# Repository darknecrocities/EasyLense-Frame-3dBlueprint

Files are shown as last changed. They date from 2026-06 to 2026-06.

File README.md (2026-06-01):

# ESP32-CAM Smart Glasses CAD Project (KCL)

An open-source, parametrically-designed, 3D-printable smart glasses frame built using **KCL (KittyCAD Language)**. This project houses two design iterations (`version1` and `version2`) of smart glasses optimized for housing an **ESP32-CAM**, rechargeable battery, charger modules, and custom routing pathways.

---

## 🕶️ Project Overview

This project provides a fully parametric CAD blueprint and print package for creating DIY smart glasses. By leveraging KCL's scripting capabilities, all clearances, frame dimensions, temple lengths, and fastener socket sizes can be customized by simply tweaking variables in the parameters file.

### Key Features
- **ESP32-CAM Integration**: Optimized compartment in the right temple to hold the microcontroller board securely.
- **Parametric Ergonomics**: Dynamic temple toe-in angle, bridge width, lens dimensions, and frame thicknesses.
- **Wire Routing & Cable Management**: Built-in strain reliefs, entry reliefs, and wiring channels for routing cables from the front frame camera to the controllers.
- **Exploded Service & Showcase Views**: Presentation layers in KCL showing how components fit together, complete with dimension annotations and fastener calls.
- **Tolerance Calibration**: Test coupons to verify printer tolerances before committing to full multi-hour temple prints.

---

## 📁 Repository Structure

The project is split into two versions, representing the evolution from a presentation-heavy assembly mockup to a print-optimized, tolerance-calibrated iteration:

```
tutorial-project/
├── version1/                      # Complete Assembly & Showcase Mockup
│   ├── main.kcl                   # Main presentation entrypoint
│   ├── parameters.kcl             # Global design variables (colors, sizes)
│   ├── front_frame.kcl            # Front glass frame CAD model
│   ├── left_temple.kcl            # Left temple arm CAD model
│   ├── right_temple.kcl           # Right temple arm (ESP32-CAM pocket)
│   ├── left_covers.kcl            # Covers for the left temple compartment
│   ├── right_covers.kcl           # Covers for the right temple compartment
│   ├── hardware.kcl               # M2 screws and heat-set insert mockups
│   ├── front_electronics.kcl      # Camera/sensor electronics model
│   ├── left_electronics.kcl       # Battery housing electronics model
│   ├── right_electronics.kcl      # ESP32-CAM board/connector models
│   ├── finished_showcase.kcl      # Closed render layout of the glasses
│   ├── dimension_blueprint.kcl    # Blueprints showing dimensional annotations
│   ├── fastener_callouts.kcl      # Assembly callouts pointing to hardware positions
│   ├── print_orientation_layout.cl# Printable parts FDM bed alignment layout
│   └── project.toml               # KCL project configuration
│
└── version2/                      # Print-Optimized & Tolerance-Calibrated Package
    ├── main.kcl                   # Minimal entrypoint showing print-ready parts
    ├── parameters.kcl             # Refined parameters with wearable toe-in angles
    ├── esp32_tolerance_coupon.kcl # Clearances test coupon for ESP32 compartment
    ├── front_frame.kcl            # Updated front frame with refined camera mounts
    ├── left_temple.kcl            # Left temple arm with refined clearances
    ├── right_temple.kcl           # Right temple arm with optimized ventilation slots
    ├── left_covers.kcl            # Left compartment covers
    ├── right_covers.kcl           # Right compartment covers
    ├── printable_assembly.kcl     # Printable part assembly references
    ├── print_ready_parts.kcl      # Flattened print layout configuration
    └── project.toml               # KCL project configuration
```

---

## 🔧 Design Iterations

### Version 1: Exploded Showcase & Assembly Blueprint
- **Focus**: Modeling the complete system architecture, assembly visualization, and presentation graphics.
- **Assembly View**: Features an exploded service view separating hardware, electronics, covers, and structural arms.
- **Dimensioning**: Contains blueprint overlays depicting model specifications.
- **Fasteners**: Includes interactive lines/annotations identifying mounting positions for M2 screws.

### Version 2: Print & Fit Calibration (Production Focus)
- **Focus**: Optimizing the design for real-world FDM 3D printing and fit comfort.
- **Wearable Fit**: Introduces ergonomic parameters like `wearableTempleToeInAngle` (defaulting to `3deg`) to curve the temples slightly inward for a secure fit on the wearer's head.
- **ESP32 Compartment Calibration**: Includes the `esp32_tolerance_coupon.kcl` test print. This creates a small compartment replica containing:
  - FDM clearance test posts.
  - Cover slide rails and M2 pilot holes.
  - Vent slot sizes and wire hooks.
  - USB charging board standoffs.
  *Use this test coupon to verify your printer's dimensional accuracy before printing the entire right temple.*
- **Print Optimization**: Simplified main assembly files to target clean `.STL`/`.STEP` output layouts.

---

## 🛠️ Usage Instructions

### 1. View & Edit in KittyCAD/KCL Editor
You can load these files into any KCL-compatible modeling viewer or the KittyCAD editor:
- Open `version1/main.kcl` to view the comprehensive presentation layout (includes showcase, exploded view, blueprints, and layouts).
- Open `version2/main.kcl` to view the final STL-ready, nested print layout.

### 2. Calibrating Tolerances (Version 2)
Prior to running a full print of the temples (which host thin walls and precise pockets):
1. Compile and print the coupon model in `version2/esp32_tolerance_coupon.kcl`.
2. Check the fitment of your ESP32-CAM board, wire routes, and sliding cover pieces.
3. If necessary, adjust tolerances in `version2/parameters.kcl` (e.g., `espFdmFitClearance`, `wallThickness`, `m2HeatSetInsertHoleDiameter`).

### 3. Slicing and Printing
- Export the parts from KCL (supports STEP, STL, and other formats).
- Recommended Slicing Settings:
  - **Layer Height**: 0.15mm - 0.2mm
  - **Infill**: 20% - 30% (gyro/grid pattern)
  - **Supports**: Required for the temple arms' internal pocket overhangs depending on orientation.
  - **Material**: PLA/PETG (recommended matte black or charcoal colors like the specified parameter HEX values).

---

## 🔩 Hardware & Bill of Materials (BOM)

- **Microcontroller**: ESP32-CAM board (approx. 43mm x 28mm).
- **USB Board**: Micro-USB or USB-C LiPo charger board (e.g., TP4056).
- **Battery**: Slim lithium-polymer rechargeable battery.
- **Screws**: M2 screws (typically 10mm length for covers).
- **Inserts**: M2 threaded heat-set inserts (3.5mm outer diameter, 4mm length).

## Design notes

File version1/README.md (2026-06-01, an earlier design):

# Smart Glasses Prototype - Version 1 (Mockup & Blueprint Assembly)

This directory contains the initial architectural mockup of the ESP32-CAM smart glasses. It is structured to generate an informative, multi-panel CAD presentation containing:
1. **Assembled View**: The fully built glasses frame with electronics nested inside.
2. **Exploded View**: Displaced components (temples, covers, electronics, screws) showing how the assembly fits together.
3. **Blueprint Panels**: Projected dimensions and annotation blueprints.
4. **Fastener Callouts**: Visual callouts illustrating screw and insert targets.
5. **Showcase Shell**: A render-ready closed configuration.
6. **Print Layout**: Parts nested onto a standard 220mm x 220mm FDM bed.

## 🚀 Entry Point

To render the full design presentation, run or compile:
```bash
main.kcl
```

## 📁 File Structure

- **`main.kcl`**: The master orchestration script compiling all assemblies and displacement panels.
- **`parameters.kcl`**: Design parameters (e.g., lens size, frame width, color codes).
- **`front_frame.kcl`**: Front glasses frames.
- **`left_temple.kcl` / `right_temple.kcl`**: Side arms.
- **`left_covers.kcl` / `right_covers.kcl`**: Sliding compartment covers.
- **`front_electronics.kcl` / `left_electronics.kcl` / `right_electronics.kcl`**: Volumes representing the physical sensors, boards, and batteries.
- **`hardware.kcl`**: Screws, washers, and insert fasteners.
- **`dimension_blueprint.kcl`**: Dimensions overlays.
- **`fastener_callouts.kcl`**: Connector annotation panel.
- **`print_orientation_layout.kcl`**: Nested printable configuration.

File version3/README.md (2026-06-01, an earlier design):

# Smart Glasses Prototype - Version 2 (Production & Tolerance Testing)

This directory houses the optimized production package of the smart glasses. The focus has shifted from assembly illustration to manufacturing validation, print nesting, and improved ergonomic wearability.

## 🚀 Entry Point

To compile the flat print package of production parts:
```bash
main.kcl
```
*(This loads the layout from `print_ready_parts.kcl` containing the structural printable components).*

## 🧪 ESP32 Clearance Tolerance Coupon

To ensure your 3D printer successfully prints the pocket snaps, sliding covers, screw slots, and cable pathways:
1. Compile and print:
   ```bash
   esp32_tolerance_coupon.kcl
   ```
2. Fit your ESP32-CAM and LiPo charging boards into the printed coupon.
3. Verify that cover panels slide in smoothly.
4. If adjustments are required, update variables in `parameters.kcl` and reprint the coupon before printing the full frame.

## 📁 Key File Changes vs Version 1

- **`parameters.kcl`**: Refined tolerances and added ergonomic `wearableTempleToeInAngle` (3deg) to fold temple tips slightly inward for a better head-fit.
- **`esp32_tolerance_coupon.kcl`**: The calibration tray representing a snippet of the controller pocket.
- **`print_ready_parts.kcl`**: Clean, printable component arrangement for slicing.

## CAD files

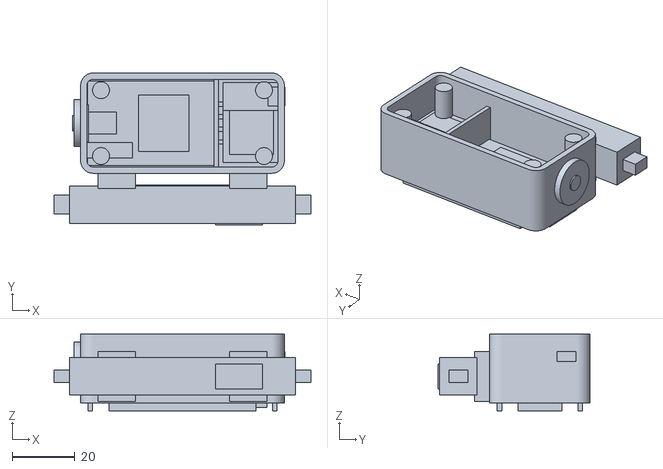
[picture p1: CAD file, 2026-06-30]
version4/main.stl
82.0 x 48.5 x 24.6

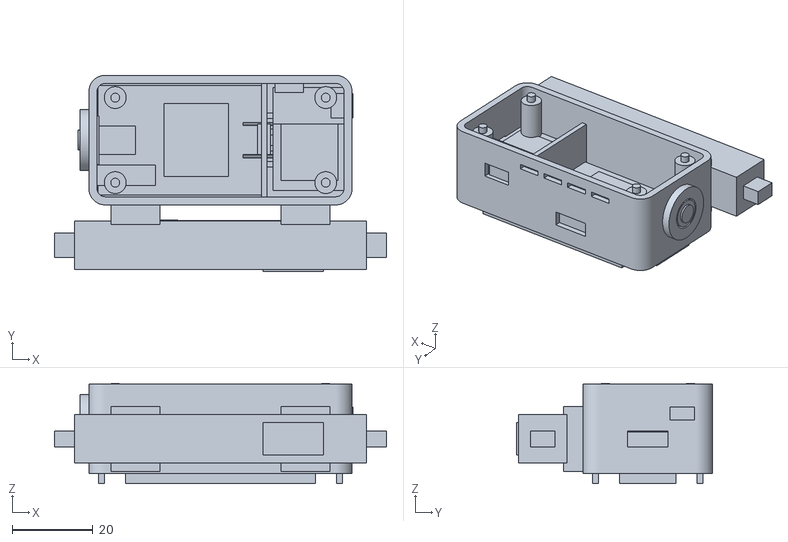
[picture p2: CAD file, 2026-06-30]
version4/complete_parts_exploded.stl
82.0 x 48.5 x 24.7

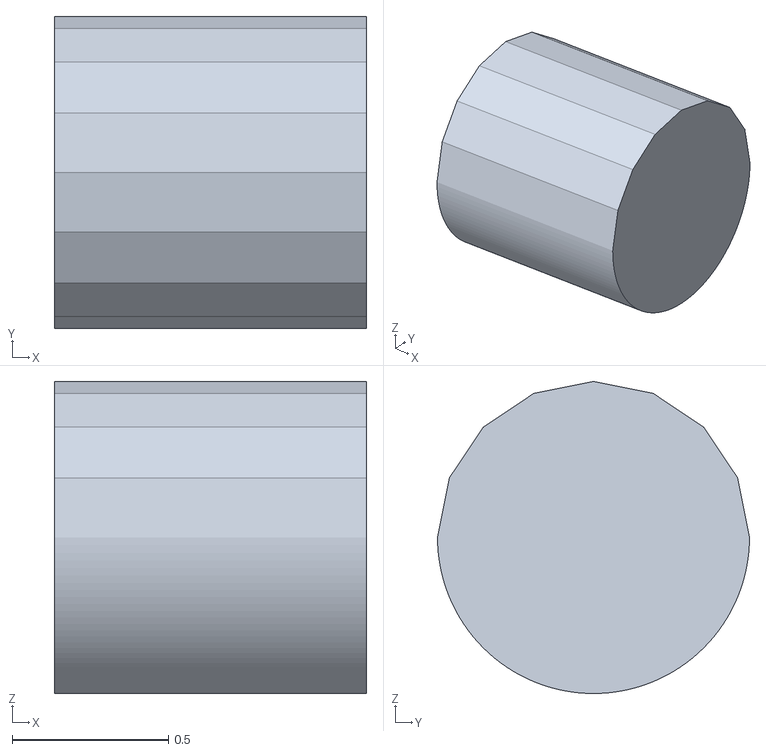
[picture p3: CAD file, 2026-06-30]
version4/unit_cyl_x.stl
1.00 x 1.00 x 1.00

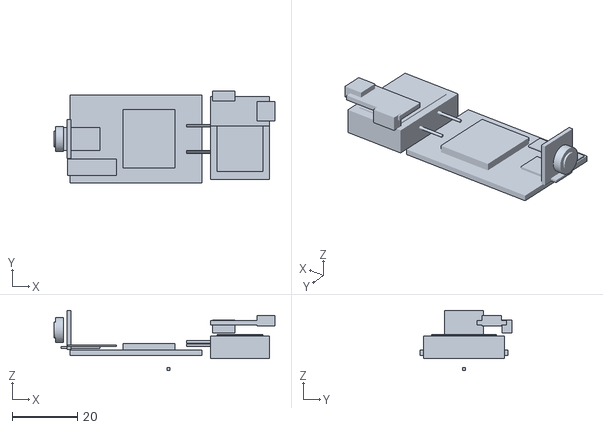
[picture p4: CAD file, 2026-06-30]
version4/electronics_placeholders.stl
67.9 x 28.2 x 18.5

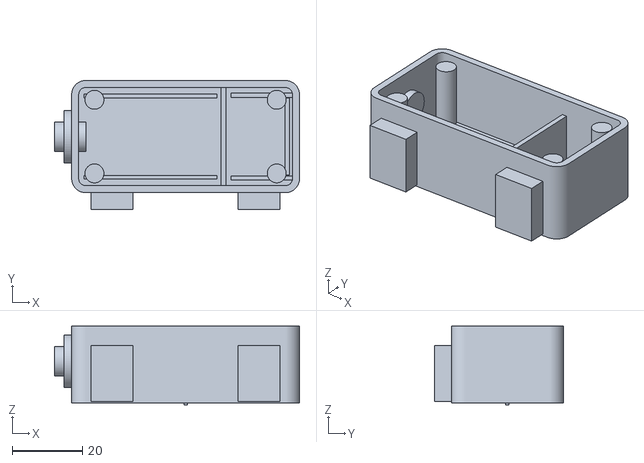
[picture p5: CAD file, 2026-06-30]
version4/smart_glasses_base.stl
69.9 x 36.8 x 22.5

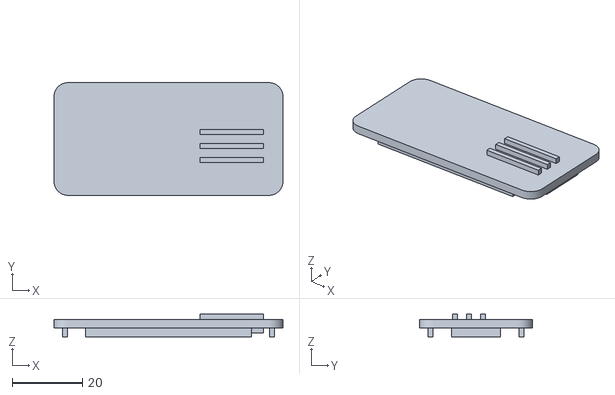
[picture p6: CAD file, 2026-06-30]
version4/smart_glasses_lid.stl
65.0 x 32.0 x 6.45

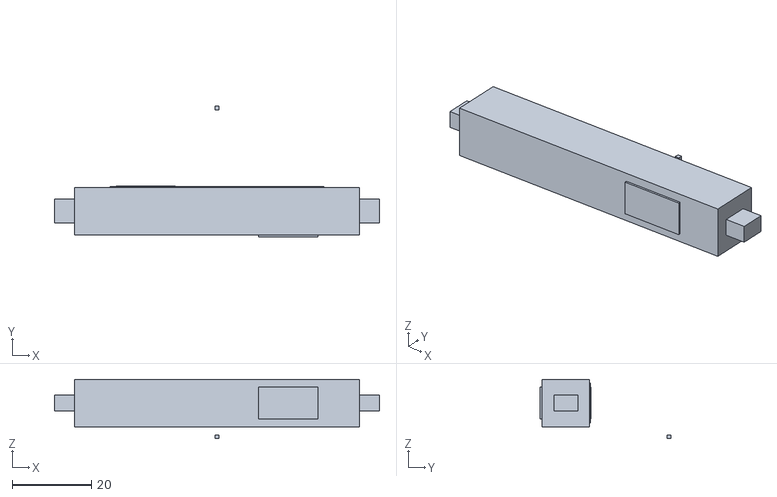
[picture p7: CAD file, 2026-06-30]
version4/velcro_mount_visual.stl
82.0 x 33.0 x 15.0

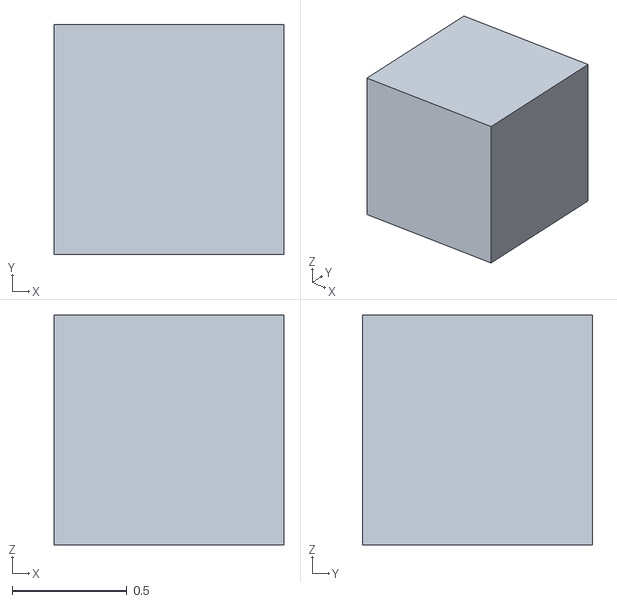
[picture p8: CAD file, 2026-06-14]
version4/unit_box.stl
1.00 x 1.00 x 1.00

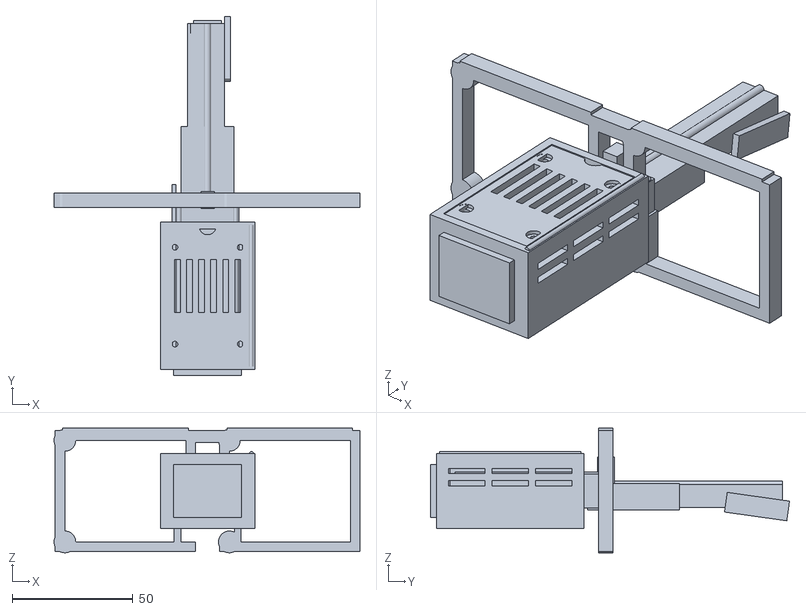
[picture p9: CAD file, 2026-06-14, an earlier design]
version3/main.stl
126.5 x 148.4 x 51.5

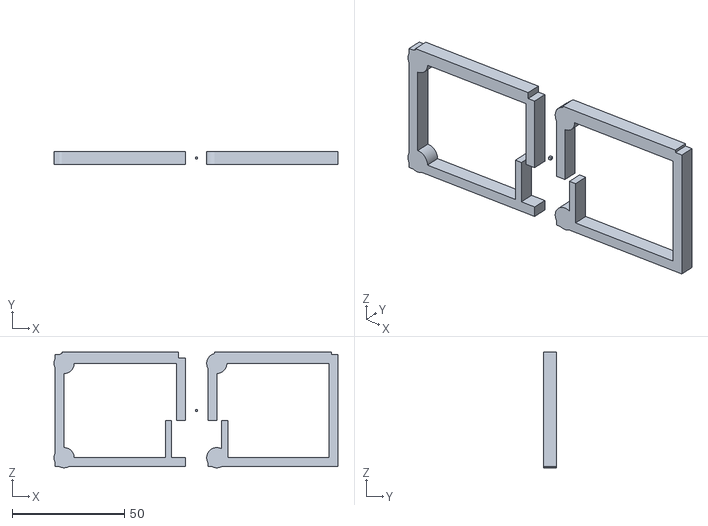
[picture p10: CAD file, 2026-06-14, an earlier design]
version3/front_frame.stl
126.5 x 6.00 x 51.5

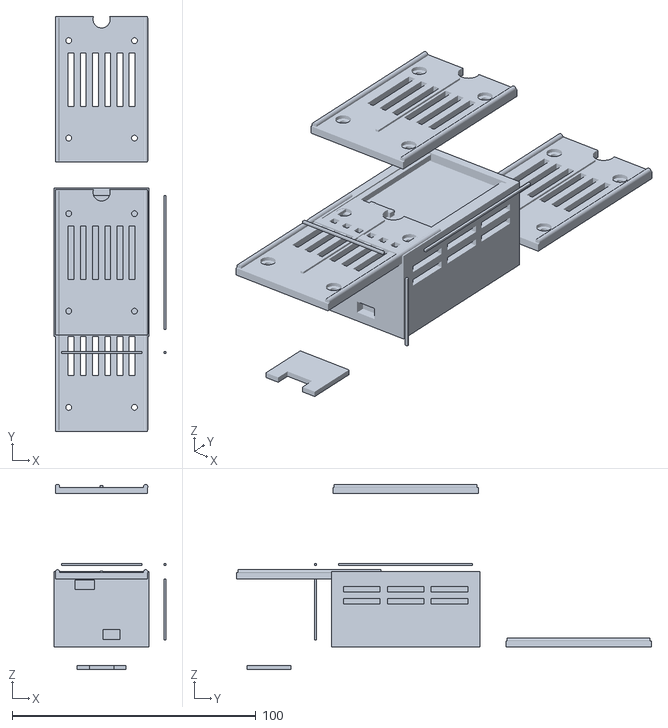
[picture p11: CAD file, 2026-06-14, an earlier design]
version3/esp32_tolerance_coupon.stl
45.9 x 170.3 x 76.1

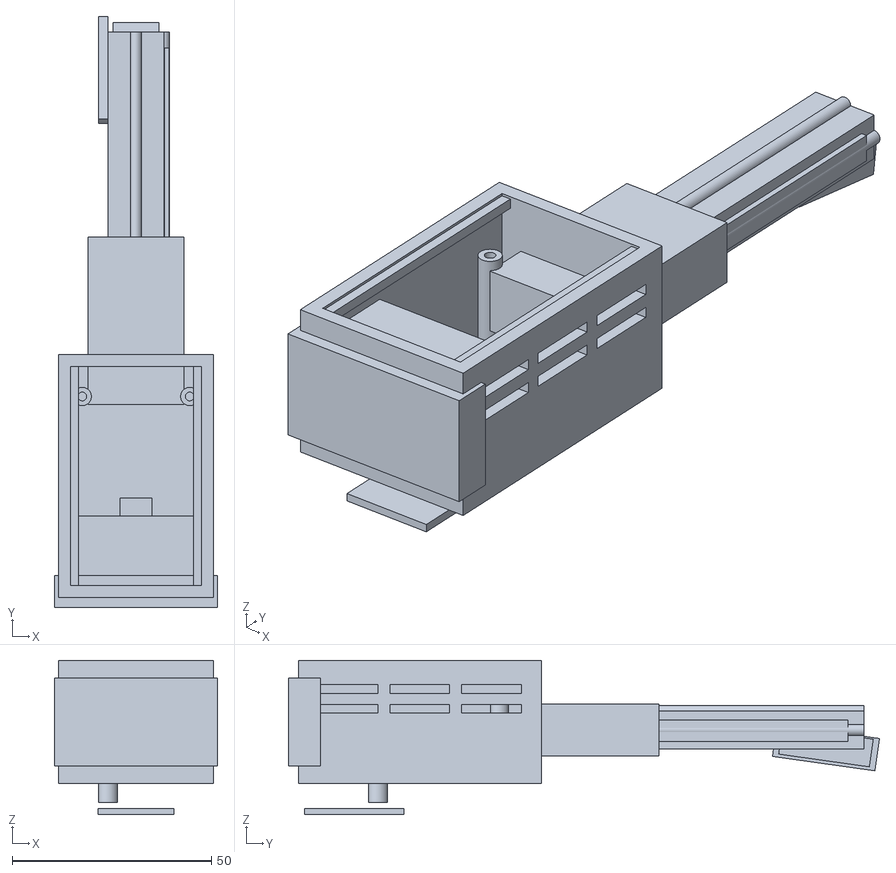
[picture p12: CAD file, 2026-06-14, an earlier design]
version3/right_temple.stl
41.0 x 148.4 x 38.8

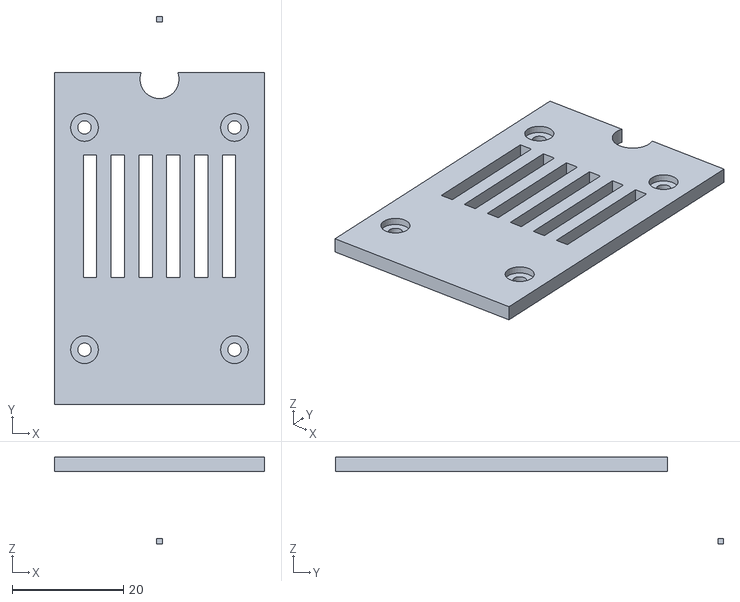
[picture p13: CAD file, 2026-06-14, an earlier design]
version3/right_covers.stl
37.8 x 69.9 x 15.6

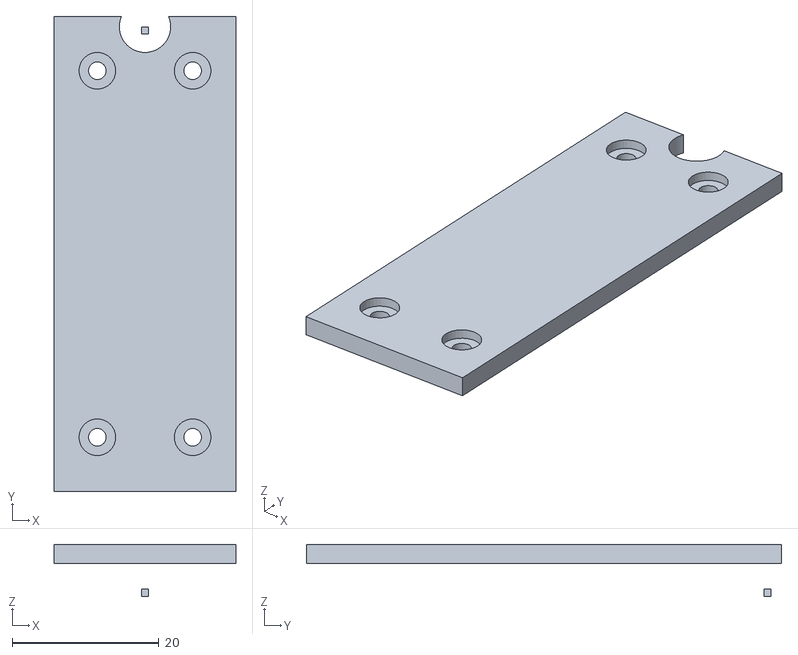
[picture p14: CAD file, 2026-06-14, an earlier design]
version3/left_covers.stl
24.8 x 64.8 x 7.10

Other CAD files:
version4/unit_cyl_y.stl
version4/unit_cyl_z.stl
version3/left_temple.stl

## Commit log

2026-06-14 add: version 3 STL files
    [esp32_tolerance_coupon.stl, front_frame.stl, left_covers.stl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]
2026-06-30 feat: adding version 4
    [complete_parts_exploded.stl, electronics_placeholders.stl, main.stl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]
